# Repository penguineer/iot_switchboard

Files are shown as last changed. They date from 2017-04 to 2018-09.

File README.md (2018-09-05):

# iot_switchboard Rev. 2 (Tapper)

Breadkout board for 2 Digitast switches with I2C/Interrupt connection

## Features:
* Suitable for up to 2 Digitast switches with or without LED (they come in various colors)
* Configurable for detection of click, double-click and hold
* Configurable LED behavior
* integrated µC takes care of debounce and I2C communication
* I2C address selectable by solder bridges
* Interrupt line tells when there is an event, so no polling necessary

Open source software and hardware!

## State of the project
  * Rev 2 PCB has been sucessfully tested
  * Open: Write firmware (there are reliable and tested debouncing algorithms, though)
  * Open: Setup and Test jig

## Get the Board
You can order the [Revision 2 Board from Oshpark](https://oshpark.com/shared_projects/GlxIHXRd/)

**Note:** QFN20 package

Top Side

Bottom Side

Soldered base board

Fully built

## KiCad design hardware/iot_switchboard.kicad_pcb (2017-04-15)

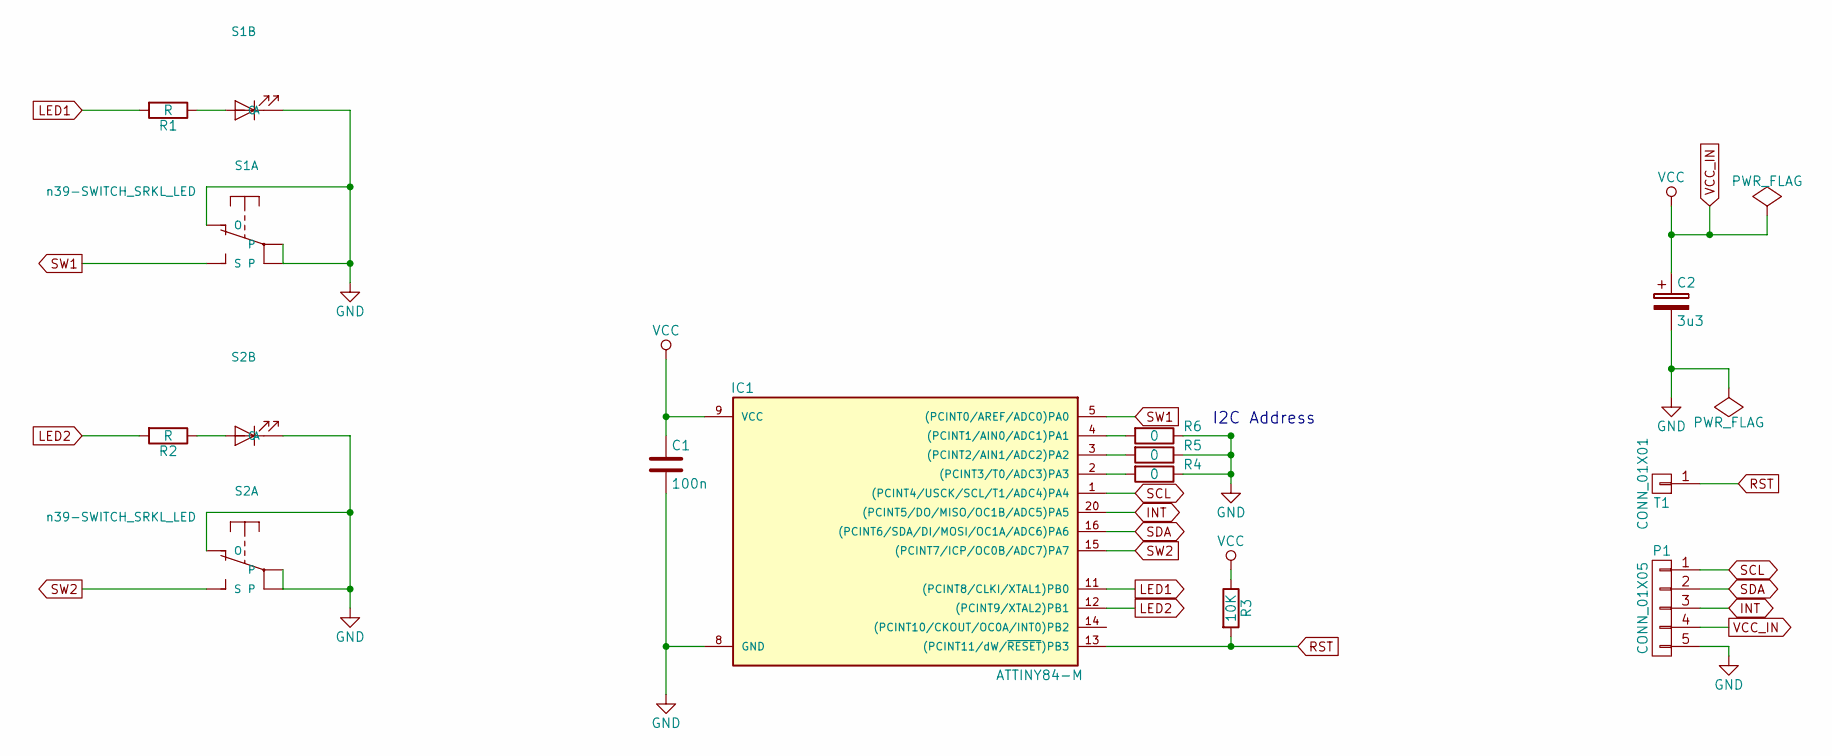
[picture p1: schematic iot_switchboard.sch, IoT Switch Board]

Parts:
C1: 100n; C_0603_HandSoldering
C2: 3u3; C_0603_HandSoldering
IC1: ATTINY84-M; QFN-20-1EP_4x4mm_Pitch0.5mm
P1: CONN_01X05; Pin_Header_Straight_1x05
R1, R2: R; Resistor_SMD+THTuniversal_0805to1206_RM10_HandSoldering
R3: 10K; R_0603_HandSoldering
R4, R5, R6: 0; R_0402
S1, S2: n39-SWITCH_SRKL_LED
T1: CONN_01X01; Measurement_Point_Round-TH_Small

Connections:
GND: C1.2, C2.2, IC1.8 (GND), P1.5, R4.1, R5.1, R6.1, S1.2, S1.3, S1.4 (O), S1.- (C), S2.2, S2.3, S2.4 (O), S2.- (C)
INT: IC1.20 ((PCINT5/DO/MISO/OC1B/ADC5)PA5), P1.3
LED1: IC1.11 ((PCINT8/CLKI/XTAL1)PB0), R1.2
LED2: IC1.12 ((PCINT9/XTAL2)PB1), R2.2
unnamed: IC1.2 ((PCINT3/T0/ADC3)PA3), R4.2
unnamed: IC1.3 ((PCINT2/AIN1/ADC2)PA2), R5.2
unnamed: IC1.4 ((PCINT1/AIN0/ADC1)PA1), R6.2
unnamed: R1.1, S1.+ (A)
unnamed: R2.1, S2.+ (A)
RST: IC1.13 ((PCINT11/dW/~RESET~)PB3), R3.2, T1.1
SCL: IC1.1 ((PCINT4/USCK/SCL/T1/ADC4)PA4), P1.1
SDA: IC1.16 ((PCINT6/SDA/DI/MOSI/OC1A/ADC6)PA6), P1.2
SW1: IC1.5 ((PCINT0/AREF/ADC0)PA0), S1.1 (S)
SW2: IC1.15 ((PCINT7/ICP/OC0B/ADC7)PA7), S2.1 (S)
VCC_IN: C1.1, C2.1, IC1.9 (VCC), P1.4, R3.1

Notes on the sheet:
I2C Address

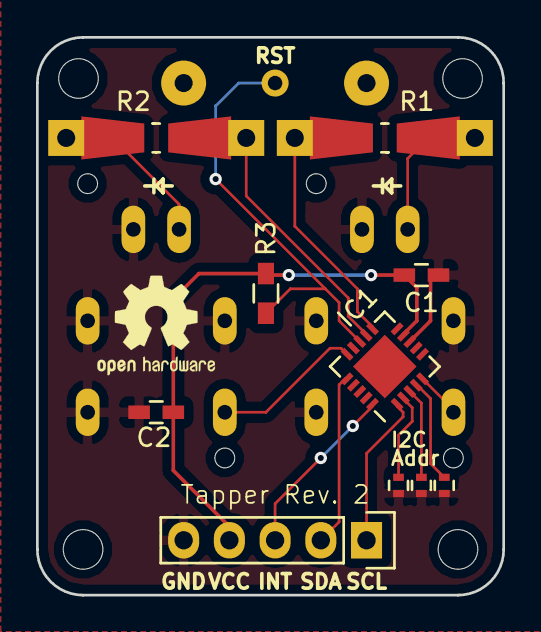
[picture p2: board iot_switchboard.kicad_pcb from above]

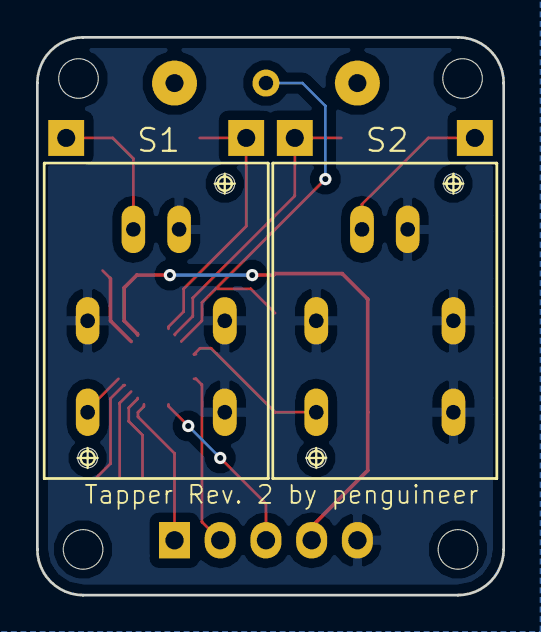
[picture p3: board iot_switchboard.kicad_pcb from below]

Board: 2 copper layers, 25.9 x 31.0 mm, 13 parts (2 on the bottom side), 15 nets.

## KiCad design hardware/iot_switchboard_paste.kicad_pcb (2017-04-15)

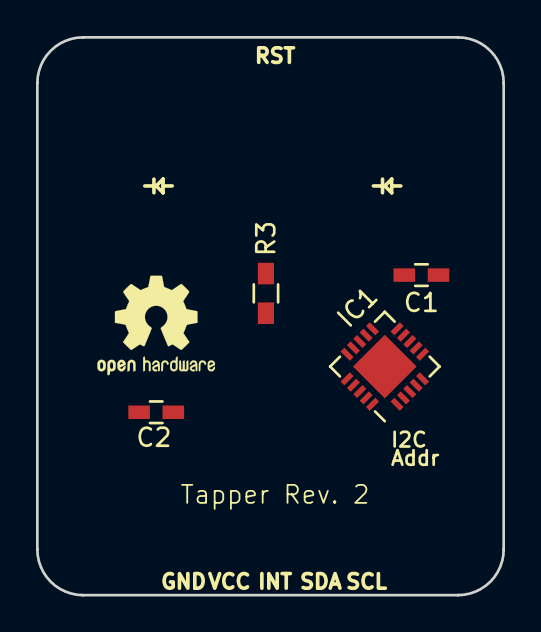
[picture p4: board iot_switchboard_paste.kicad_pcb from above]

Board: 2 copper layers, 25.9 x 31.0 mm, 4 parts (0 on the bottom side), 3 nets, no tracks yet.

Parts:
C1: 100n; C_0603_HandSoldering
C2: 3u3; C_0603_HandSoldering
IC1: ATTINY84-M; QFN-20-1EP_4x4mm_Pitch0.5mm
R3: 10K; R_0603_HandSoldering

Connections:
GND: C1.2, C2.2, IC1.8
RST: IC1.13, R3.2
VCC_IN: C1.1, C2.1, IC1.9, R3.1

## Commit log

2017-03-18 KiCad gitignore for hardware folder
2017-03-18 first hardware revision: schematic and started layout
    [iot_switchboard.kicad_pcb, iot_switchboard.sch]
2017-03-18 layout and attiny in QFN20
    [iot_switchboard.kicad_pcb, iot_switchboard.sch]
2017-03-21 Adapt to Oshpark design rules
    [iot_switchboard.kicad_pcb]
2017-04-14 Replace load capacitor by 0603 type
    [iot_switchboard.kicad_pcb, iot_switchboard.sch]
2017-04-14 Reduce to 2 switches and adapt outline
    [iot_switchboard.kicad_pcb, iot_switchboard.sch]
2017-04-15 New Layout
    Yeah!
    [iot_switchboard.kicad_pcb, iot_switchboard.sch]
2017-04-15 Copy the board with only pre-populated compontens
    Needed for the solder mask
    [iot_switchboard_paste.kicad_pcb]
2017-04-17 Update the Readme to the current project state
